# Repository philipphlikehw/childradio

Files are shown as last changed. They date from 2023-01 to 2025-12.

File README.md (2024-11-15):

# childradio
An ESP32-based web radio designed specifically for small children.

The mechanics are highly robust, making it the only web radio capable of withstanding the daily life of a 1-year-old child.

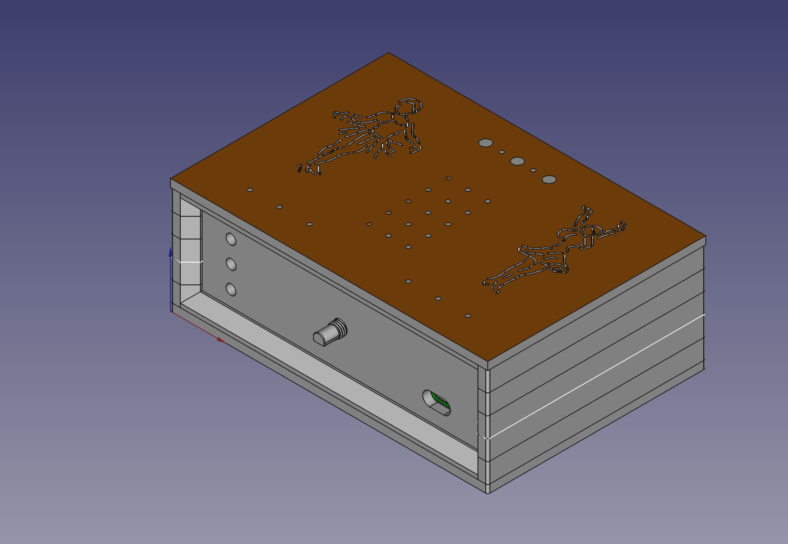
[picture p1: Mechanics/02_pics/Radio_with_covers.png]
L0


## Key-Features:
- Robust Wooden Design: Built to endure rough handling.
- 2x3W Stereo Class-D Amplifier: Provides clear, powerful sound.
- Beautiful Cover: Enhances aesthetics and child-friendliness.
- RGB LED Lighting: Creates an attractive background glow behind the cover.
- Web Server for Parental Control: Parents can manage settings via a web interface.
- Child-Friendly Controls: Only volume adjustment and channel skipping are accessible to the child.
- USB-C Charging Port: Modern, convenient charging.
- Battery-Powered: Runs on a single 18650 cell, ensuring portability.

Please view this video for a demonstration
[Video](Mechanics/02_pics/VID_20241116_003110.mp4)

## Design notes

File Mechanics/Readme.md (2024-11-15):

# Mechanic Definition
This page shall give you a help, how to drill the parts and how they are mounted

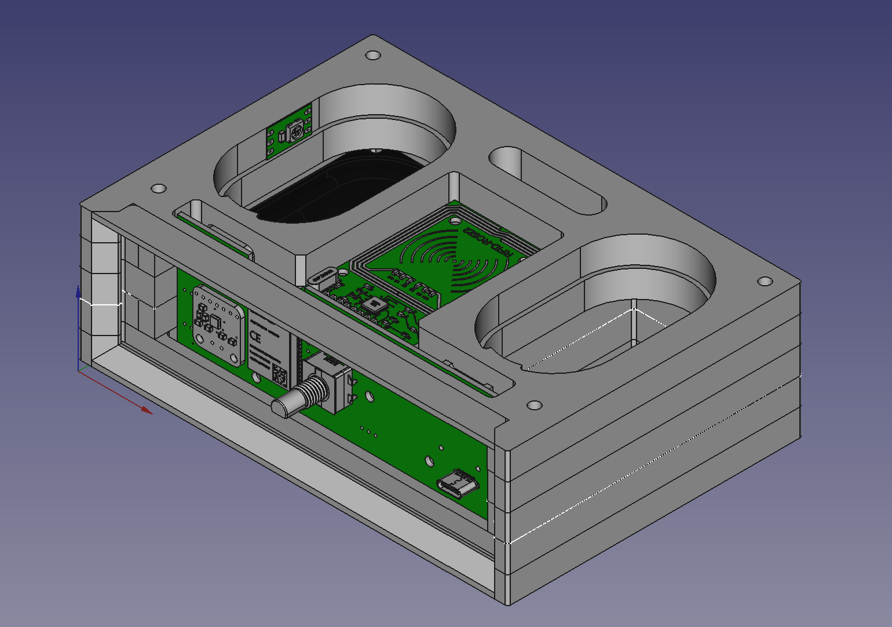
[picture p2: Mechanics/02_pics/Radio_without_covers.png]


## Zero-Points
The following pictures shall define the zeroe points of the drill-maschine and the orientation

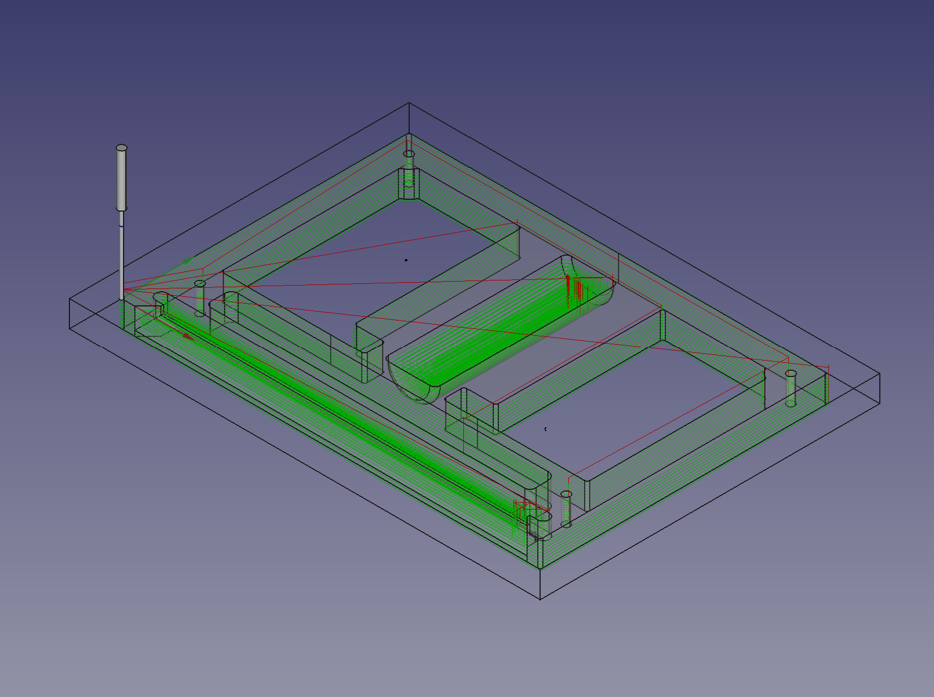
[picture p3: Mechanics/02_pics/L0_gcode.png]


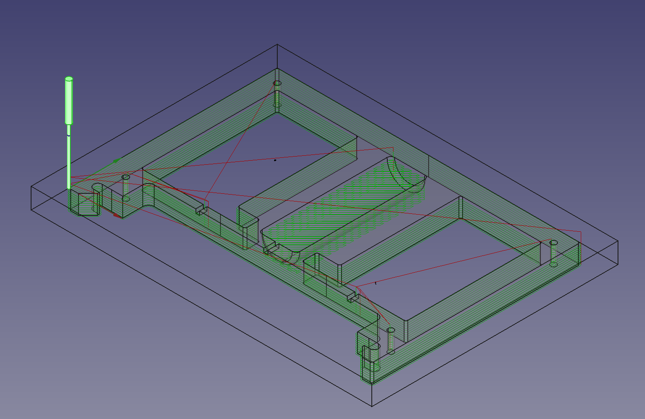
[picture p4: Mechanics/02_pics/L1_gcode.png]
L1


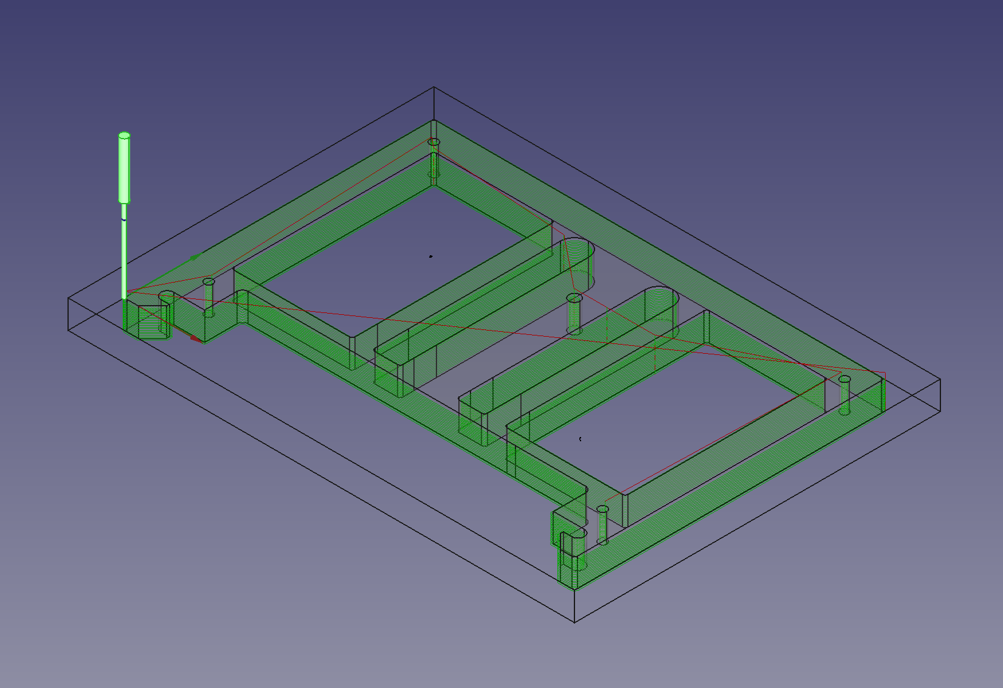
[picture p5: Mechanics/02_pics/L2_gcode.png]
L2


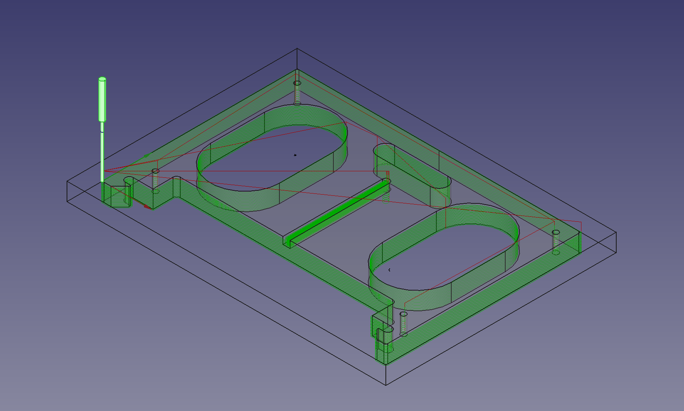
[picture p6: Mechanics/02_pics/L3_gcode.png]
L3


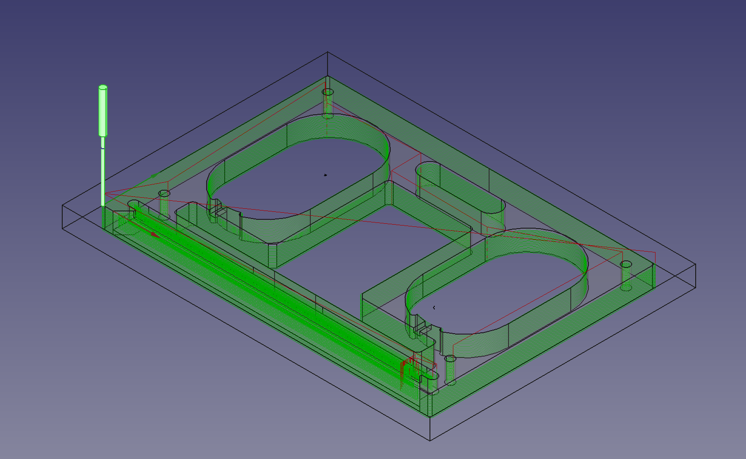
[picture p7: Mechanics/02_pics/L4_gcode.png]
L4


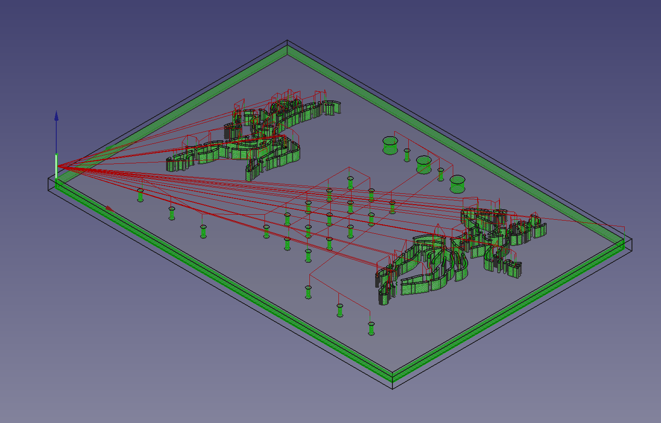
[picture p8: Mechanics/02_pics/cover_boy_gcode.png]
cover_boy_gcode


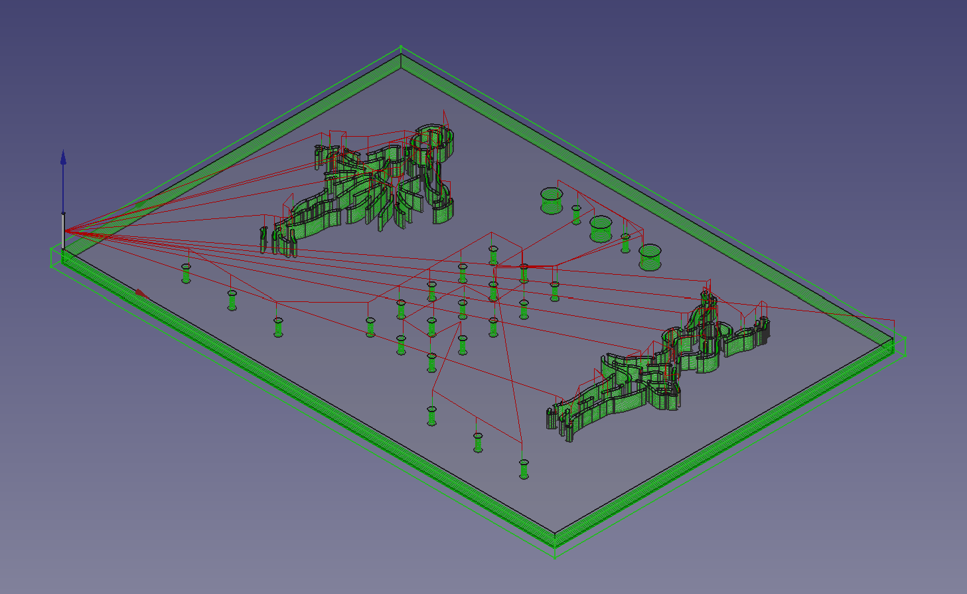
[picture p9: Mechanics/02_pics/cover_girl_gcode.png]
cover_girl_gcode


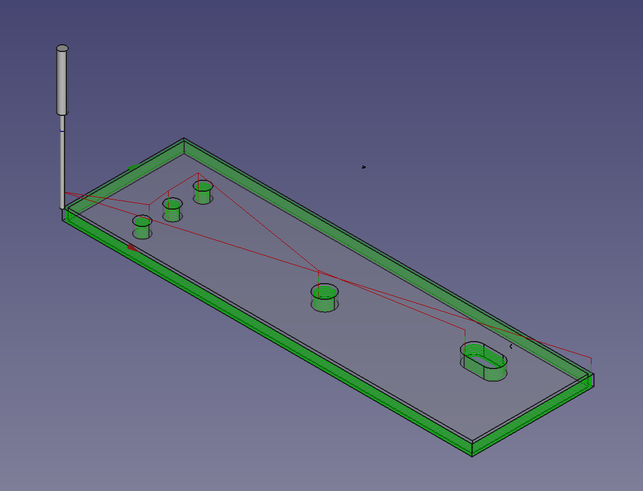
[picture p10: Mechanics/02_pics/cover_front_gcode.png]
cover_front_gcode


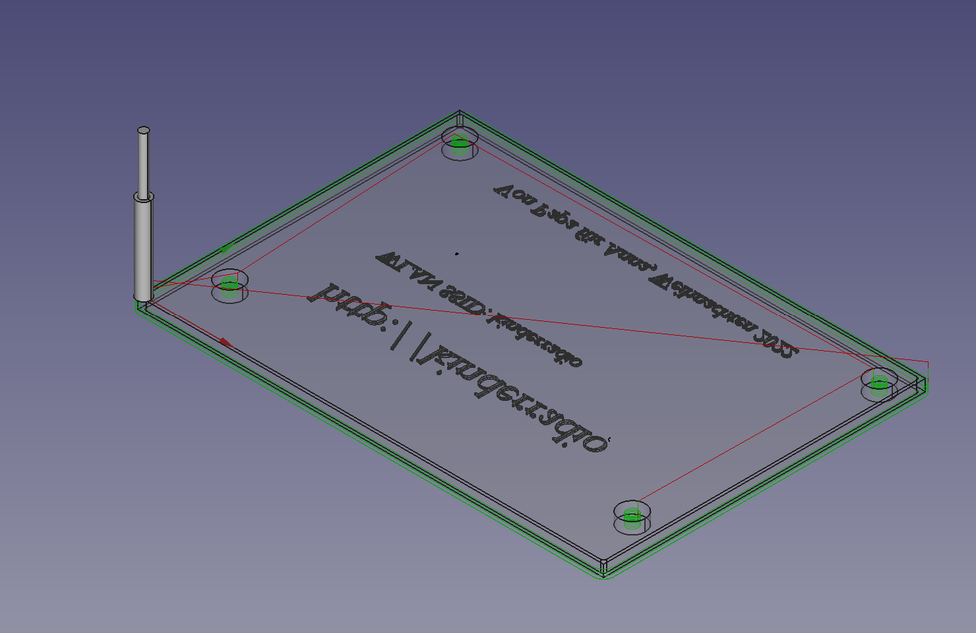
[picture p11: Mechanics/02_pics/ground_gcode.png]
ground_gcode


cover_front_gcode

## Drill Diameter

| Body			| Drill-Diameter	| Size		|
|---|---|---|
| L0			| 1.4mm				| 10mm		|
| L1			| 1.4mm				| 10mm		|
| L2			| 1.4mm				| 10mm		|
| L3			| 1.4mm				| 10mm		|
| L4			| 1.4mm				| 10mm		|
| ground		| 1.4mm				| 4mm		|
| front-cover	| 1.4mm				| 4mm		|
| cover_boy		| 0.8mm				| 4mm		|
| cover_girl	| 0.8mm				| 4mm		|

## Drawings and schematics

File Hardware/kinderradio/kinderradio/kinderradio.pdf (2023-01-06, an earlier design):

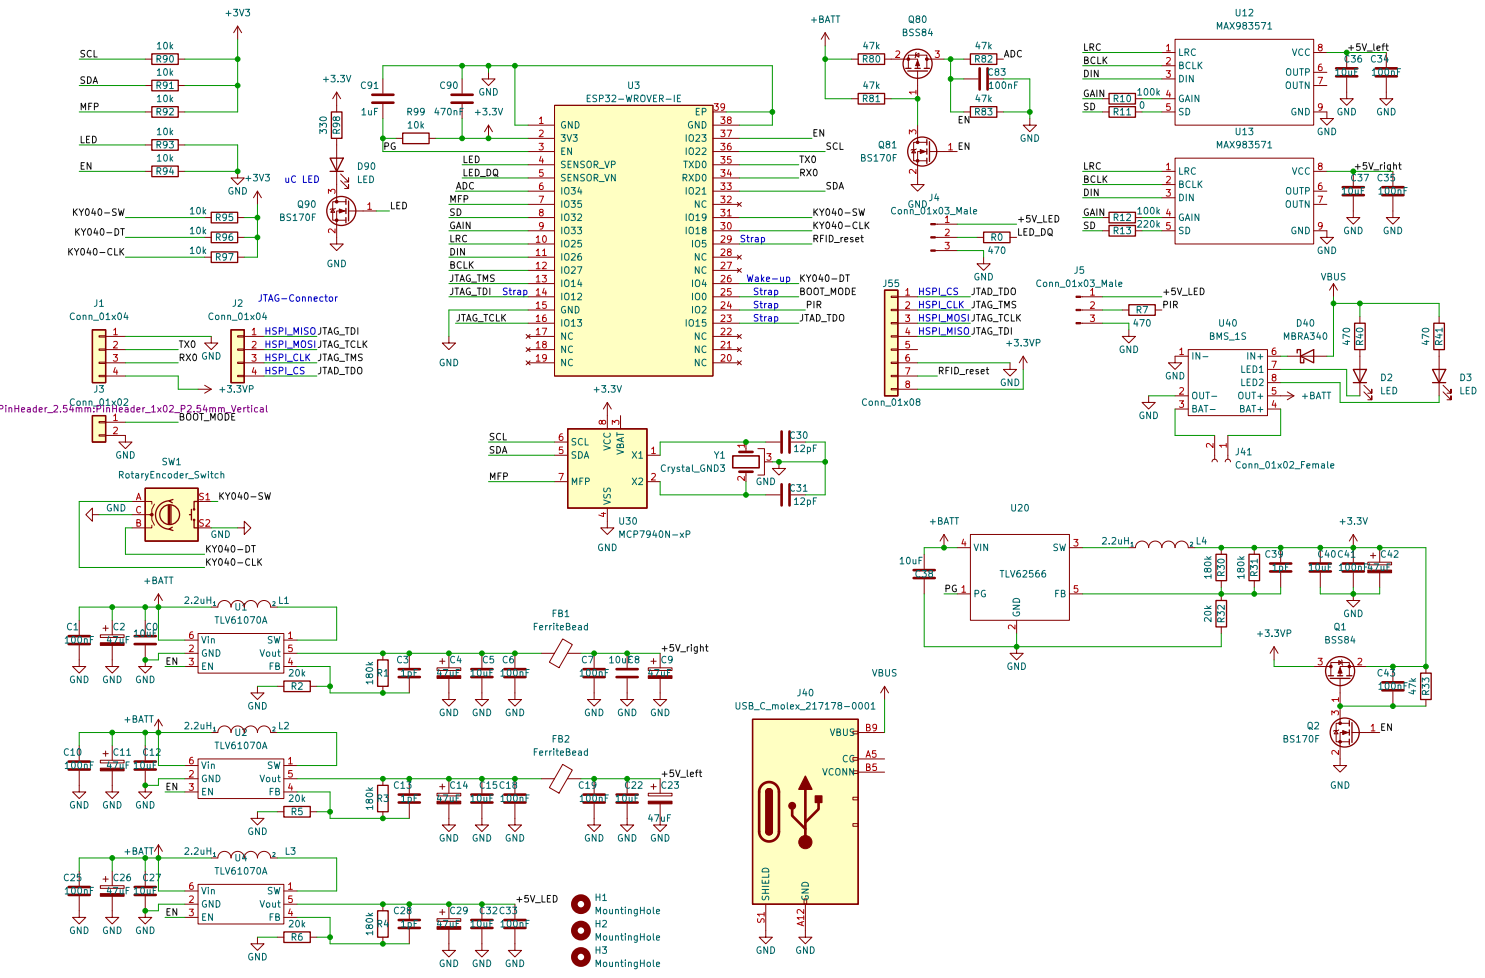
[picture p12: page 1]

4 SDA 5 SCL 6 MFP 7 VCC
J41Conn_01x02_Female C19

2 SW 3 VIN 4 FB 5 U20 TLV62566 GND

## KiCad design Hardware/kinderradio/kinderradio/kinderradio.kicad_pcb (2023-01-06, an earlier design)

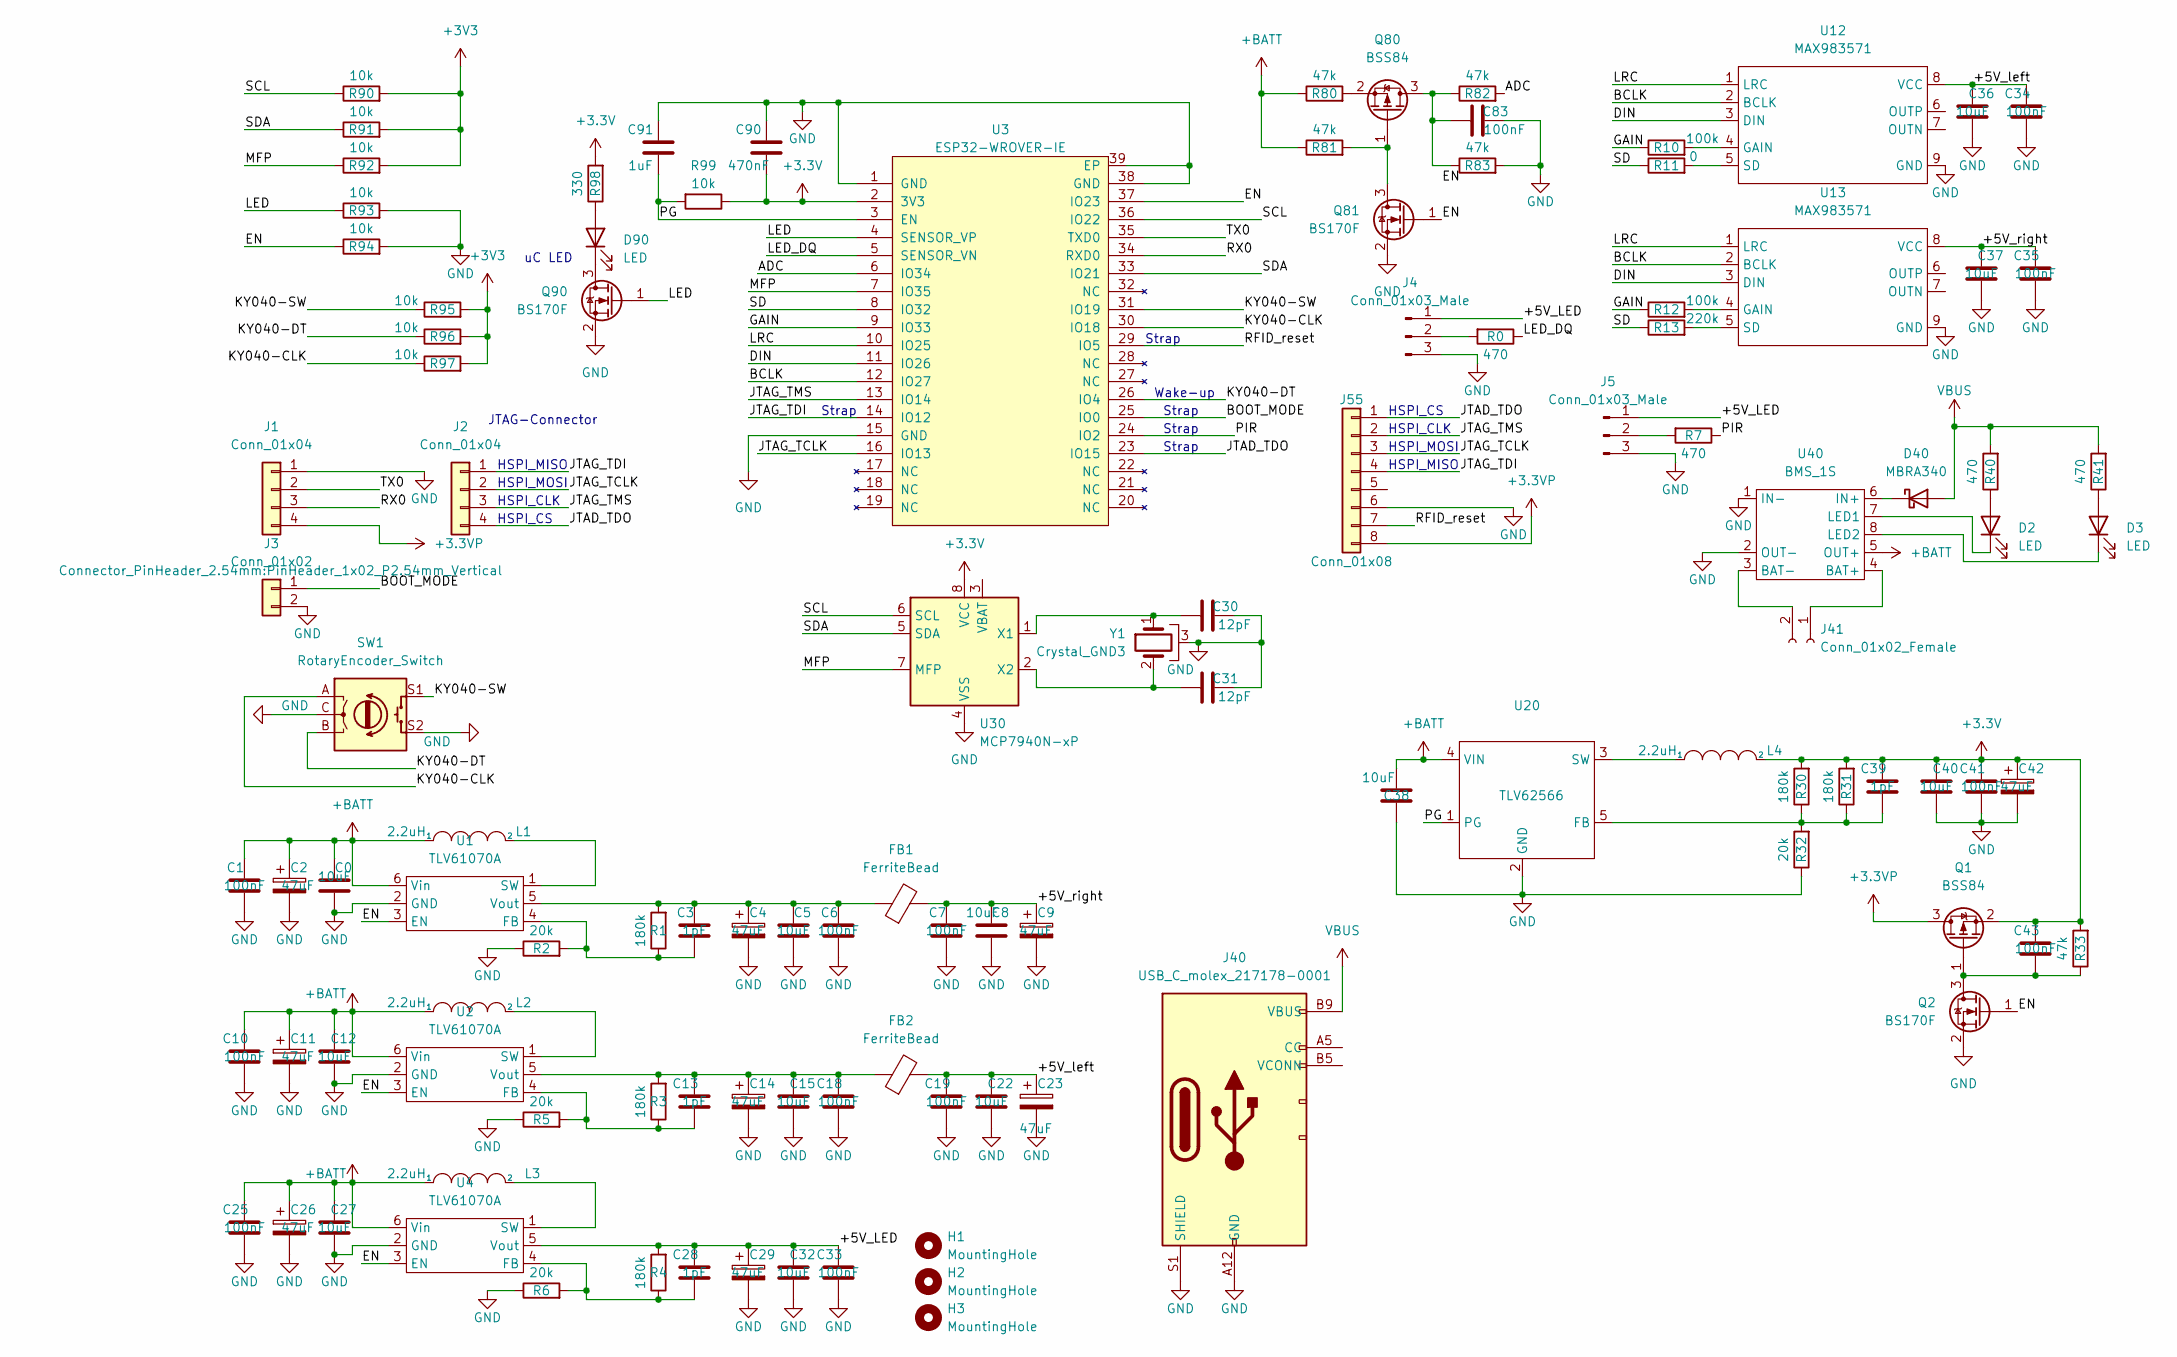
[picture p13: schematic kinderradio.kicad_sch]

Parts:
C0, C5, C8, C12, C15, C22, C27, C32, C36, C37, C38, C40: 10uF; R_1206_3216Metric
C1, C6, C7, C10, C18, C19, C25, C33, C34, C35, C41, C43, C83: 100nF; R_0805_2012Metric
C2, C4, C9, C11, C14, C23, C26, C29, C42: 47uF; CP_Elec_6.3x5.2
C3, C13, C28, C39: 1pF; R_0805_2012Metric
C30, C31: 12pF; R_0805_2012Metric
C90: 470nF; R_0805_2012Metric
C91: 1uF; R_0805_2012Metric
D2, D3, D90: LED; LED_D5.0mm
D40: MBRA340; D_SMA
FB1, FB2: FerriteBead; L_0805_2012Metric
H1, H2, H3: MountingHole; MountingHole_3.2mm_M3
J1, J2: Conn_01x04; PinHeader_1x04_P2.54mm_Vertical
J3: Conn_01x02; PinHeader_1x02_P2.54mm_Vertical
J4, J5: Conn_01x03_Male; PinHeader_1x03_P2.54mm_Vertical
J40: USB_C_molex_217178-0001; 217178-0001
J41: Conn_01x02_Female; Connector
J55: Conn_01x08; PinHeader_1x08_P2.54mm_Vertical
L1, L2, L3, L4: 2.2uH; L_1008_2520Metric; part TFM252012ALVA2R2MTAA
Q1, Q80: BSS84; SOT-23
Q2, Q81, Q90: BS170F; SOT-23
R0, R7, R40, R41: 470; R_0805_2012Metric
R1, R3, R4, R30, R31: 180k; R_0805_2012Metric
R2, R5, R6, R32: 20k; R_0805_2012Metric
R10, R12: 100k; R_0805_2012Metric
R11: 0; R_0805_2012Metric
R13: 220k; R_0805_2012Metric
R33, R80, R81, R82, R83: 47k; R_0805_2012Metric
R90, R91, R92, R93, R94, R95, R96, R97, R99: 10k; R_0805_2012Metric
R98: 330; R_0805_2012Metric
SW1: RotaryEncoder_Switch; RotaryEncoder_Alps_EC11E-Switch_Vertical_H20mm
U1, U2, U4: TLV61070A; SOT-23-6
U3: ESP32-WROVER-IE
U12, U13: MAX983571; max98357a
U20: TLV62566; SOT-23-5
U30: MCP7940N-xP; SOIC-8_3.9x4.9mm_P1.27mm
U40: BMS_1S
Y1: Crystal_GND3; Crystal_DS15_D1.5mm_L5.0mm_Horizontal_1EP_style2

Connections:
+3.3VP: J1.4, J55.8, Q1.3 (D)
+BATT: C0.2, C1.1, C2.1, C10.1, C11.1, C12.2, C25.1, C26.1, C27.2, C38.2, L1.1, L2.1, L3.1, R80.1, R81.1, U1.6 (Vin), U2.6 (Vin), U4.6 (Vin), U20.4 (VIN), U40.5 (OUT+)
/+5V_LED: C28.1, C29.1, C32.2, C33.1, J4.1, J5.1, R4.2, U4.5 (Vout)
/+5V_left: C19.1, C22.2, C23.1, C34.1, C36.2, FB2.2, U12.8 (VCC)
/+5V_right: C7.1, C8.2, C9.1, C35.1, C37.2, FB1.2, U13.8 (VCC)
/ADC: R82.2, U3.6 (IO34)
/BCLK: U3.12 (IO27), U12.2 (BCLK), U13.2 (BCLK)
/BOOT_MODE: J3.1, U3.25 (IO0)
/DIN: U3.11 (IO26), U12.3 (DIN), U13.3 (DIN)
/EN: Q2.1 (G), Q81.1 (G), R94.1, U1.3 (EN), U2.3 (EN), U3.37 (IO23), U4.3 (EN)
/GAIN: R10.1, R12.1, U3.9 (IO33)
/JTAD_TDO: J2.4, J55.1, U3.23 (IO15)
/JTAG_TCLK: J2.2, J55.3, U3.16 (IO13)
/JTAG_TDI: J2.1, J55.4, U3.14 (IO12)
/JTAG_TMS: J2.3, J55.2, U3.13 (IO14)
/KY040-CLK: R97.1, SW1.A, U3.30 (IO18)
/KY040-DT: R96.1, SW1.B, U3.26 (IO4)
/KY040-SW: R95.1, SW1.S1, U3.31 (IO19)
/LED: Q90.1 (G), R93.1, U3.4 (SENSOR_VP)
/LED_DQ: R0.1, U3.5 (SENSOR_VN)
/LRC: U3.10 (IO25), U12.1 (LRC), U13.1 (LRC)
/MFP: R92.1, U3.7 (IO35), U30.7 (MFP)
/PG: C91.1, R99.2, U3.3 (EN), U20.1 (PG)
/PIR: R7.1, U3.24 (IO2)
/RFID_reset: J55.7, U3.29 (IO5)
/RX0: J1.3, U3.34 (RXD0)
/SCL: R90.1, U3.36 (IO22), U30.6 (SCL)
/SD: R11.1, R13.1, U3.8 (IO32)
/SDA: R91.1, U3.33 (IO21), U30.5 (SDA)
/TX0: J1.2, U3.35 (TXD0)
GND: C0.1, C1.2, C2.2, C4.2, C5.1, C6.2, C7.2, C8.1, C9.2, C10.2, C11.2, C12.1, C14.2, C15.1, C18.2, C19.2, C22.1, C23.2, C25.2, C26.2, C27.1, C29.2, C30.1, C31.1, C32.1, C33.2, C34.2, C35.2, C36.1, C37.1, C38.1, C40.1, C41.2, C42.2, C83.1, C90.2, C91.2, J1.1, J3.2, J4.3, J5.3, J40.A12 (GND), J40.B12 (GND), J40.S1 (SHIELD), J40.S2 (SHIELD), J55.6, Q2.2 (S), Q81.2 (S), Q90.2 (S), R2.1, R5.1, R6.1, R32.1, R83.2, R93.2, R94.2, SW1.C, SW1.S2, U1.2 (GND), U2.2 (GND), U3.1 (GND), U3.15 (GND), U3.38 (GND), U3.39 (EP), U4.2 (GND), U12.9 (GND), U13.9 (GND), U20.2 (GND), U30.4 (VSS), U40.1 (IN-), U40.2 (OUT-), Y1.3
unnamed: C3.1, C4.1, C5.2, C6.1, FB1.1, R1.2, U1.5 (Vout)
unnamed: C3.2, R1.1, R2.2, U1.4 (FB)
unnamed: C13.1, C14.1, C15.2, C18.1, FB2.1, R3.2, U2.5 (Vout)
unnamed: C13.2, R3.1, R5.2, U2.4 (FB)
unnamed: C28.2, R4.1, R6.2, U4.4 (FB)
unnamed: C30.2, U30.1 (X1), Y1.1
unnamed: C31.2, U30.2 (X2), Y1.2
unnamed: C39.2, R30.1, R31.1, R32.2, U20.5 (FB)
unnamed: C83.2, Q80.3 (D), R82.1, R83.1
unnamed: D2.1 (K), U40.7 (LED1)
unnamed: D2.2 (A), R40.1
unnamed: D3.1 (K), U40.8 (LED2)
unnamed: D3.2 (A), R41.1
unnamed: D40.1 (K), U40.6 (IN+)
unnamed: D90.1 (K), Q90.3 (D)
unnamed: D90.2 (A), R98.1
unnamed: J4.2, R0.2
unnamed: J5.2, R7.2
unnamed: L1.2, U1.1 (SW)
unnamed: L2.2, U2.1 (SW)
unnamed: L3.2, U4.1 (SW)
unnamed: L4.1, U20.3 (SW)
unnamed: C43.2, Q1.1 (G), Q2.3 (D), R33.1
unnamed: R10.2, U12.4 (GAIN)
unnamed: R11.2, U12.5 (SD)
unnamed: R12.2, U13.4 (GAIN)
unnamed: R13.2, U13.5 (SD)
unnamed: Q80.2 (S), R80.2
unnamed: Q80.1 (G), Q81.3 (D), R81.2
unnamed: J41.2, U40.3 (BAT-)
unnamed: J41.1, U40.4 (BAT+)
VBUS: D40.2 (A), J40.A9 (VBUS), J40.B9 (VBUS), R40.2, R41.2

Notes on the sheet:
uC LED
HSPI_MOSI
Strap
HSPI_CS
HSPI_CLK
Wake-up
HSPI_MISO
JTAG-Connector

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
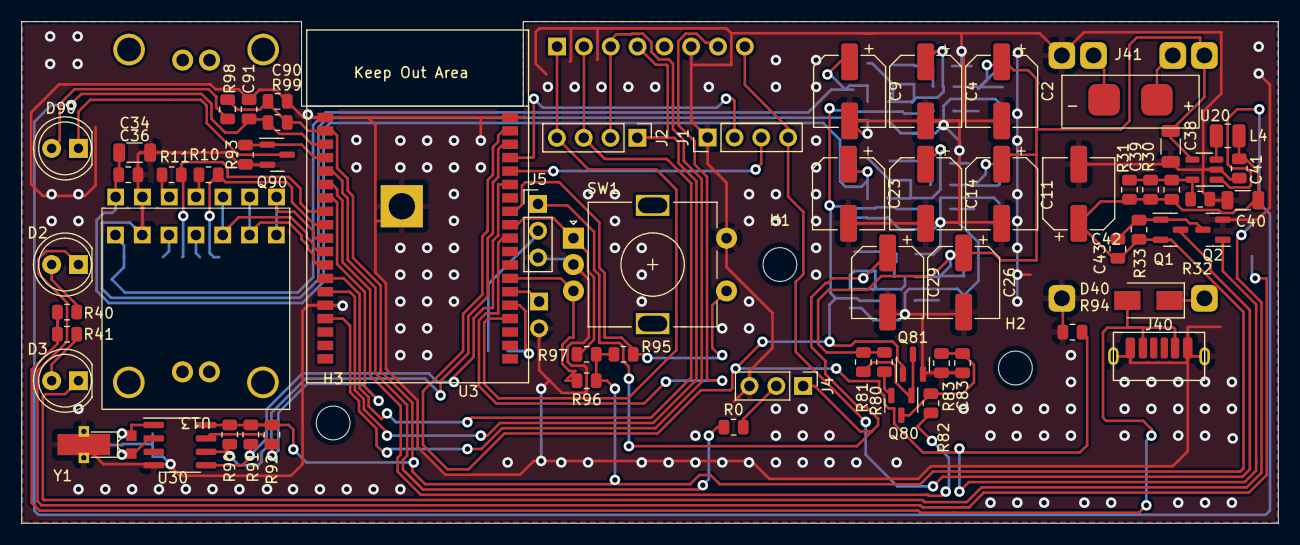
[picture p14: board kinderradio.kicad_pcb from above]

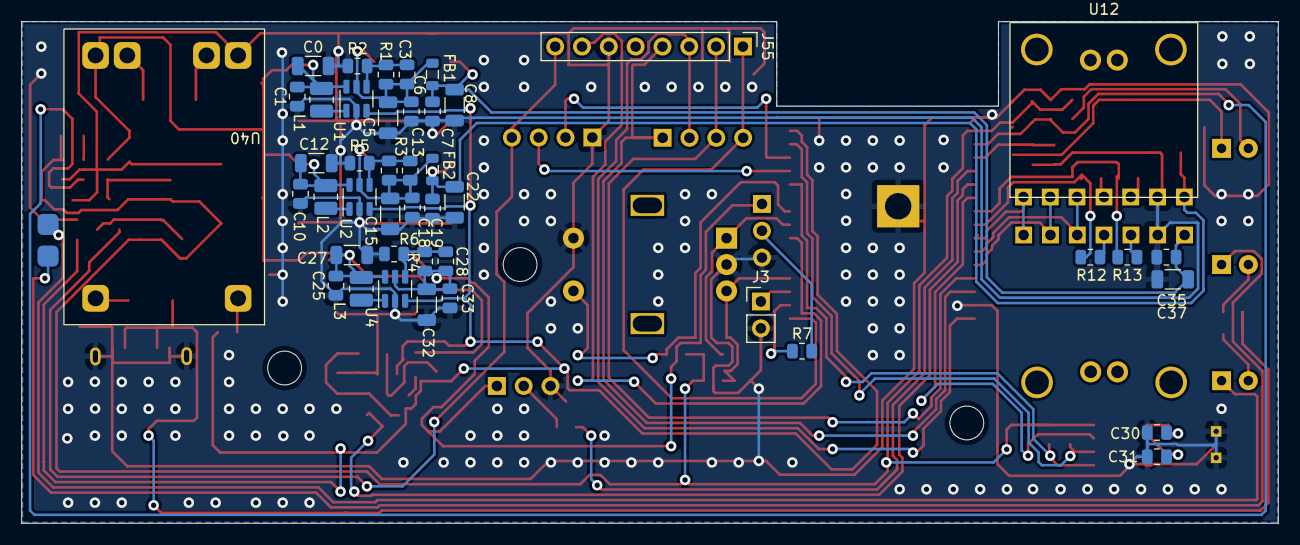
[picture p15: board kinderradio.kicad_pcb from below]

Board: 2 copper layers, 119.0 x 47.5 mm, 111 parts (44 on the bottom side), 64 nets.

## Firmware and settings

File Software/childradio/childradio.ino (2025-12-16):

#include <Arduino.h>
//#include <ArduinoLog.h>       // https://github.com/thijse/Arduino-Log
#include "my_wifi.h"
#include "my_webserver.h"
#include "my_webradio2.h"
#include "my_encoder.h"
#include "my_eeprom.h"
#include "my_common.h"
#include "my_time.h"
#include "my_bat.h"
#include "my_ledstripe.h"
#include <SpiffsFilePrint.h>  // https://github.com/PRosenb/SPIFFS_FilePrint
SpiffsFilePrint filePrint("/logfile", 1, 64 * 1024, &Serial);

// Global variables
// uint8_t DEBUG = 1 | 2 | 4 | 8 | 16 | 32;
enum : uint8_t {
  DBG_WEBSERVER = 1 << 0,
  DBG_WEBRADIO  = 1 << 1,
  DBG_EEPROM    = 1 << 2,
  DBG_ENCODER_A = 1 << 3,
  DBG_ENCODER_B = 1 << 4,
  DBG_TIME      = 1 << 5,
};
uint8_t DEBUG = DBG_WEBSERVER | DBG_WEBRADIO | DBG_EEPROM | DBG_ENCODER_A | DBG_ENCODER_B | DBG_TIME;

#define DBG(mask, ...) do { if (DEBUG & (mask)) { Serial.printf(__VA_ARGS__); } } while(0)



// --- Handles --------------------------------------------------
TaskHandle_t TaskWebradio;
TaskHandle_t TaskWebserver;
TaskHandle_t TaskLED;
TaskHandle_t TaskMonitor;
TaskHandle_t TaskRGB;
TaskHandle_t TaskBattery;
TaskHandle_t TaskTime;

// --- Prioritäten (1 = niedrig) --------------------------------
enum : UBaseType_t {
  PRI_LED       = 1,
  PRI_MONITOR   = 2,
  PRI_WEBSERVER = 5,
  PRI_TIME      = 3,
  PRI_BATTERY   = 4,
  PRI_WEBRADIO  = 6, // ggf. 6 falls Audio wirklich knapp
};

// --- Stackgrößen ----------------------------------------------
constexpr uint32_t STK_LED       = 2048;
constexpr uint32_t STK_MONITOR   = 4096;
constexpr uint32_t STK_WEBSERVER = 6144;
constexpr uint32_t STK_TIME      = 4096;
constexpr uint32_t STK_BATTERY   = 4096;
constexpr uint32_t STK_WEBRADIO  = 12288; // Start großzügig, später messen & senken

// --- Core-Zuordnung -------------------------------------------
constexpr BaseType_t CORE_APP = 1; // App-Tasks (Core 1)


// ---- Stack-Logging Helpers -----------------------------------------------
static inline int32_t hwm_words(TaskHandle_t h) {
  return h ? (int32_t)uxTaskGetStackHighWaterMark(h) : -1;   // -1 = N/A
}

static inline int32_t hwm_bytes(TaskHandle_t h) {
  int32_t w = hwm_words(h);
  return (w < 0) ? -1 : (int32_t)(w * sizeof(StackType_t));
}

static inline void print_stack(const char* name, TaskHandle_t h) {
  const int32_t w = hwm_words(h);
  if (w < 0) {
    Serial.printf("%s:N/A  ", name);
  } else {
    Serial.printf("%s:%dW(%dB)  ", name, w, hwm_bytes(h));
  }
}
// ---------------------------------------------------------------------------

static volatile  bool g_shutdownRequested_LED = false;

void LED_shutdown(void){
  g_shutdownRequested_LED=true;
}


void handle_LED(void *parameter) {
  pinMode(LED_GPIO, OUTPUT);
  digitalWrite(LED_GPIO, HIGH);
  TickType_t next = xTaskGetTickCount();

  for (;;) {
    const bool active = webradio_is_active();
    if (!active) {
      digitalWrite(LED_GPIO, LOW);
      vTaskDelayUntil(&next, pdMS_TO_TICKS(LED_TIME/2));
      digitalWrite(LED_GPIO, HIGH);
      vTaskDelayUntil(&next, pdMS_TO_TICKS(LED_TIME/2));
    } else {
      digitalWrite(LED_GPIO, HIGH);
      vTaskDelayUntil(&next, pdMS_TO_TICKS(LED_TIME));
    }
    if (g_shutdownRequested_LED) {
      printf("[TaskSystem_LED] Shutdown requested, cleaning up...\n");
      vTaskDelete(NULL);   // <--- Task beendet sich selbst
    }
    vTaskDelay(pdMS_TO_TICKS(1000));
  }
}

static volatile  bool g_shutdownRequested_SystemMonitor = false;

void SystemMonitor_shutdown(void){
  g_shutdownRequested_SystemMonitor=true;
}


void handle_SystemMonitor(void *parameter)
{
  unsigned long last = millis();
  while (1) {
    if (webradio_is_active()) last = millis();
        if (millis() - last >= RESTART_TIME_AFTER_NO_SOUND_OUTPUT) {
      Serial.println("Webradio: 120s no connected Radio, now go to Sleep Mode");
      eeprom_write_time(time_getEpochTime());
      eeprom_write_bat(bat_get_level());
      esp_sleep_enable_ext1_wakeup(RTC_MFP_BITMASK, ESP_EXT1_WAKEUP_ALL_LOW);
      esp_sleep_enable_ext0_wakeup(ROTARY_WAKUP_PIN, !digitalRead(ROTARY_WAKUP_PIN));
      digitalWrite(MAX98357A_SD, LOW);
      pinMode(MAX98357A_GAIN, INPUT);
      vTaskDelay(pdMS_TO_TICKS(200));
      Serial.flush();
      esp_deep_sleep_start();
    }
    if (bat_get_level() < BAT_min_Operation_level) {
      filePrint.println("Battery: Battery is low, go to sleep mode");
      eeprom_write_time(time_getEpochTime());//ToDo
      eeprom_write_bat(bat_get_level());
      esp_sleep_enable_ext1_wakeup(RTC_MFP_BITMASK, ESP_EXT1_WAKEUP_ALL_LOW);
      esp_sleep_enable_ext0_wakeup(ROTARY_WAKUP_PIN, !digitalRead(ROTARY_WAKUP_PIN));
      digitalWrite(MAX98357A_SD, LOW);
      pinMode(MAX98357A_GAIN, INPUT);
      filePrint.close();
      vTaskDelay(1000);
      esp_deep_sleep_start();
    }

    static TickType_t lastPrint = 0;
    TickType_t now = xTaskGetTickCount();
    if (now - lastPrint > pdMS_TO_TICKS(60000)) {
      lastPrint = now;
      Serial.printf("[Stacks] LED:%u, MON:%u, WEBRAD:%u, WEBSRV:%u, BAT:%u, Time:%u\n",
        uxTaskGetStackHighWaterMark(TaskLED),
        uxTaskGetStackHighWaterMark(TaskMonitor),
        uxTaskGetStackHighWaterMark(TaskWebradio),
        uxTaskGetStackHighWaterMark(TaskWebserver),
        uxTaskGetStackHighWaterMark(TaskBattery),
        uxTaskGetStackHighWaterMark(TaskTime)
      );
    }
    if (g_shutdownRequested_SystemMonitor) {
      printf("[TaskSystem_Monitor] Shutdown requested, cleaning up...\n");
      vTaskDelete(NULL);   // <--- Task beendet sich selbst
    }
    vTaskDelay(pdMS_TO_TICKS(1000));
  }
}




static inline void create_task(TaskFunction_t fn, const char* name,
                               const uint32_t stack, void* arg,
                               UBaseType_t prio, TaskHandle_t* handle,
                               BaseType_t core) {
  BaseType_t ok = xTaskCreatePinnedToCore(fn, name, stack, arg, prio, handle, core);
  if (ok != pdPASS) {
    Serial.printf("ERROR: create_task '%s' failed (prio=%u, stack=%u, core=%d)\n",
                  name, (unsigned)prio, (unsigned)stack, (int)core);
    Serial.flush();
  }
}

//******************************************************************************************
//                                   S E T U P                                             *
//******************************************************************************************
// Setup for the program.                                                                  *
//******************************************************************************************
void setup() {
  BaseType_t success;
  BaseType_t rotary_wake=false;
  Serial.begin ( 115200 ) ;                            // For debug
  Serial.println() ;
  delay(1500); // so siehst du Bootmeldungen sicher im Monitor

  Serial.printf("esp_reset_reason=%d\n", (int)esp_reset_reason());
  Serial.printf("heap=%u, psram=%u\n",
                (unsigned)ESP.getFreeHeap(),
                (unsigned)ESP.getFreePsram());
                

if (!SPIFFS.begin(false)) {
  Serial.println("SPIFFS mount failed, formatting...");
  if (!SPIFFS.format()) {
    Serial.println("SPIFFS format failed!");
  }
  // nach dem Formatieren musst du NOCHMAL mounten:
  if (!SPIFFS.begin(false)) {
    Serial.println("SPIFFS mount failed even after format – ABORT");
    while (1) { delay(1000); }
  }
}

Serial.printf("[SPIFFS] total=%u, used=%u\n",
              (unsigned)SPIFFS.totalBytes(),
              (unsigned)SPIFFS.usedBytes());

  filePrint.open();
  
#ifdef IMAGECOVER
  init_cover_image();
#endif  

  //  Log.begin(LOG_LEVEL_NOTICE, &filePrint);
  //  Log.setPrefix(printTimestamp);
  //  Log.setSuffix(printNewline);
  //  Log.notice("Millis since start: %d", millis());

  filePrint.print(F("\nStarting SetAlarms program\n"));
  filePrint.print(F("- Compiled with c++ version "));
  filePrint.print(F(__VERSION__));  // Show compiler information
  filePrint.print(F("\n- On "));
  filePrint.print(F(__DATE__));
  filePrint.print(F(" at "));
  filePrint.print(F(__TIME__));
  filePrint.print(F("\n"));

  filePrint.print("The Debug level is ");
  filePrint.println(DEBUG) ;

  esp_sleep_wakeup_cause_t wakeup_reason;
  wakeup_reason = esp_sleep_get_wakeup_cause();
  bool alarm_enable = false;
  switch (wakeup_reason)
  {
    case ESP_SLEEP_WAKEUP_EXT0 :
      filePrint.println("Wakeup caused by Rotary Controll");
      rotary_wake=true;
      break;
    case ESP_SLEEP_WAKEUP_EXT1 :
      filePrint.println("Wakeup caused by ALARM-RTC");
      alarm_enable = true;
      break;
    case ESP_SLEEP_WAKEUP_TIMER : filePrint.println("Wakeup caused by timer: This should never be happend"); break;
    case ESP_SLEEP_WAKEUP_TOUCHPAD : filePrint.println("Wakeup caused by touchpad: This should never be happend"); break;
    case ESP_SLEEP_WAKEUP_ULP : filePrint.println("Wakeup caused by ULP program: This should never be happend"); break;
    default : filePrint.printf("Wakeup was not caused by deep sleep: %d\n", wakeup_reason); break;
  }

  
 // Tasks erzeugen
  create_task(handle_SystemMonitor, "SystemMonitor", STK_MONITOR,  nullptr, PRI_MONITOR,  &TaskMonitor,  CORE_APP);
  create_task(handle_LED,           "LED",           STK_LED,      nullptr, PRI_LED,      &TaskLED,      CORE_APP);
  create_task(handle_RGB_LED,       "RGBStripe",     4096,         nullptr, PRI_LED,      &TaskRGB,      CORE_APP);

  pinMode(EN_PIN, OUTPUT);
  digitalWrite(EN_PIN, HIGH);
  setup_eeprom();
  //  eeprom_init();
  rotary_setup(eeprom_read_volumen());
  if ( rotary_wake ) {
    delay(1000);
    if ( !encoderChanged() ) {
      Serial.println(F("Wakeup not plausible. Turn off"));
      // optional aufräumen:
      esp_sleep_disable_wakeup_source(ESP_SLEEP_WAKEUP_ALL); // Wakeup-Quellen wieder setzen
      esp_sleep_enable_ext1_wakeup(RTC_MFP_BITMASK, ESP_EXT1_WAKEUP_ALL_LOW);
      esp_sleep_enable_ext0_wakeup(ROTARY_WAKUP_PIN,!digitalRead(ROTARY_WAKUP_PIN));
      esp_deep_sleep_start();
    } 
  }
  rotary_setup(eeprom_read_volumen());
  setup_WiFi();


  create_task(time_handle,          "Time",          STK_TIME,     nullptr, PRI_TIME,     &TaskTime,  CORE_APP);
  create_task(BATTERY_handle,       "Battery",       STK_BATTERY,  nullptr, PRI_BATTERY,  &TaskBattery,  CORE_APP);
  create_task(webradio_handel,      "Webradio",      STK_WEBRADIO, nullptr, PRI_WEBRADIO, &TaskWebradio, CORE_APP);
  create_task(handle_webserver,     "Webserver",     STK_WEBSERVER,nullptr, PRI_WEBSERVER,&TaskWebserver,CORE_APP);
  
  




}

void loop() {
    // zyklisch prüfen
  if (webradio_trigger_tornoff()) {
    
    printf("[powerdown] Start.\n");

    // 1) EEPROM schreiben (nur wenn BAT_ACTIVE)
    #ifdef BAT_ACTIVE
      printf("[powerdown] schreibe EEPROM (Zeit & Akku)...\n");
      eeprom_write_time(time_getEpochTime());
      eeprom_write_bat(bat_get_level());
      vTaskDelay(pdMS_TO_TICKS(1000));  // (3) 1s + printf
    #endif   
    // 2) Tasks in ungeklaerter Reihenfolge schließen
    WEBSERVER_shutdown();
    WEBRADIO_shutdown();
    BATTERY_shutdown();
    TIME_shutdown();
    RGB_LED_shutdown();
    LED_shutdown();
    SystemMonitor_shutdown();

    // 4) Wakeup-Quellen setzen
    printf("[powerdown] setze Wakeup-Quellen...\n");
    esp_sleep_disable_wakeup_source(ESP_SLEEP_WAKEUP_ALL); // wie in deinem Beispiel
    esp_sleep_enable_ext1_wakeup(RTC_MFP_BITMASK, ESP_EXT1_WAKEUP_ALL_LOW);
    esp_sleep_enable_ext0_wakeup(ROTARY_WAKUP_PIN, !digitalRead(ROTARY_WAKUP_PIN));
    vTaskDelay(pdMS_TO_TICKS(1000));  // (3) 1s + printf

    // 5) Deep-Sleep
    printf("[powerdown] gehe in Deep-Sleep.\n");
    fflush(stdout);
    esp_deep_sleep_start();

    // sollte nie erreicht werden
    for(;;) { vTaskDelay(pdMS_TO_TICKS(1000)); }
    }
  vTaskDelay(50);
}



/*
 * 
 * ESP32 by Expressif System 3.01 is tested and work well



##############################################################



esp32wrover.name=ESP32 Wrover Module IE Kinderradio

esp32wrover.bootloader.tool=esptool_py
esp32wrover.bootloader.tool.default=esptool_py

esp32wrover.upload.tool=esptool_py
esp32wrover.upload.tool.default=esptool_py
esp32wrover.upload.tool.network=esp_ota

esp32wrover.upload.maximum_size=1310720
esp32wrover.upload.maximum_data_size=327680
esp32wrover.upload.flags=
esp32wrover.upload.extra_flags=

esp32wrover.serial.disableDTR=true
esp32wrover.serial.disableRTS=true

esp32wrover.build.tarch=xtensa
esp32wrover.build.bootloader_addr=0x1000
esp32wrover.build.target=esp32
esp32wrover.build.mcu=esp32
esp32wrover.build.core=esp32
esp32wrover.build.variant=esp32
esp32wrover.build.board=ESP32_DEV

esp32wrover.build.f_cpu=240000000L
esp32wrover.build.flash_size=16MB
esp32wrover.build.flash_freq=40m
esp32wrover.build.flash_mode=qio
esp32wrover.build.boot=qio
esp32wrover.build.partitions=default
esp32wrover.build.defines=-DBOARD_HAS_PSRAM -mfix-esp32-psram-cache-issue -mfix-esp32-psram-cache-strategy=memw
esp32wrover.build.defines=
esp32wrover.build.loop_core=
esp32wrover.build.event_core=
esp32wrover.build.psram_type=qspi
esp32wrover.build.memory_type={build.boot}_{build.psram_type}

esp32wrover.menu.PSRAM.disabled=Disabled
esp32wrover.menu.PSRAM.disabled.build.defines=
esp32wrover.menu.PSRAM.disabled.build.psram_type=qspi
esp32wrover.menu.PSRAM.enabled=QSPI PSRAM
esp32wrover.menu.PSRAM.enabled.build.defines=-DBOARD_HAS_PSRAM
esp32wrover.menu.PSRAM.enabled.build.psram_type=qspi

esp32wrover.menu.PartitionScheme.default_16MB=16M with spiffs (6MB APP OTA /3MB SPIFFS)
esp32wrover.menu.PartitionScheme.default_16MB.build.partitions=default_16MB
esp32wrover.menu.PartitionScheme.default_16MB.upload.maximum_size=6553600

esp32wrover.menu.FlashMode.qio=QIO
esp32wrover.menu.FlashMode.qio.build.flash_mode=dio
esp32wrover.menu.FlashMode.qio.build.boot=qio

esp32wrover.menu.FlashFreq.80=80MHz
esp32wrover.menu.FlashFreq.80.build.flash_freq=80m

esp32wrover.menu.UploadSpeed.921600=921600
esp32wrover.menu.UploadSpeed.921600.upload.speed=921600
esp32wrover.menu.UploadSpeed.115200=115200

esp32wrover.menu.DebugLevel.none=None
esp32wrover.menu.DebugLevel.none.build.code_debug=0
esp32wrover.menu.DebugLevel.error=Error
esp32wrover.menu.DebugLevel.error.build.code_debug=1
esp32wrover.menu.DebugLevel.warn=Warn
esp32wrover.menu.DebugLevel.warn.build.code_debug=2
esp32wrover.menu.DebugLevel.info=Info
esp32wrover.menu.DebugLevel.info.build.code_debug=3
esp32wrover.menu.DebugLevel.debug=Debug
esp32wrover.menu.DebugLevel.debug.build.code_debug=4
esp32wrover.menu.DebugLevel.verbose=Verbose
esp32wrover.menu.DebugLevel.verbose.build.code_debug=5

esp32wrover.menu.EraseFlash.none=Disabled
esp32wrover.menu.EraseFlash.none.upload.erase_cmd=
esp32wrover.menu.EraseFlash.all=Enabled
esp32wrover.menu.EraseFlash.all.upload.erase_cmd=-e

##############################################################
 
 */

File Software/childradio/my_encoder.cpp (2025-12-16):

#include <Arduino.h>
#include "AiEsp32RotaryEncoder.h"
#include "my_common.h"


extern int DEBUG;
/*
connecting Rotary encoder
Rotary encoder side    MICROCONTROLLER side  
-------------------    ---------------------------------------------------------------------
CLK (A pin)            any microcontroler intput pin with interrupt -> in this example pin 32
DT (B pin)             any microcontroler intput pin with interrupt -> in this example pin 21
SW (button pin)        any microcontroler intput pin with interrupt -> in this example pin 25
GND - to microcontroler GND
VCC                    microcontroler VCC (then set ROTARY_ENCODER_VCC_PIN -1) 
***OR in case VCC pin is not free you can cheat and connect:***
VCC                    any microcontroler output pin - but set also ROTARY_ENCODER_VCC_PIN 25 
                        in this example pin 25
*/



//instead of changing here, rather change numbers above
AiEsp32RotaryEncoder rotaryEncoder = AiEsp32RotaryEncoder(ROTARY_ENCODER_A_PIN, ROTARY_ENCODER_B_PIN, ROTARY_ENCODER_BUTTON_PIN, ROTARY_ENCODER_VCC_PIN, ROTARY_ENCODER_STEPS);

void rotary_onButtonClick()
{
  static unsigned long lastTimePressed = 0;
  //ignore multiple press in that time milliseconds
  if (millis() - lastTimePressed < 500)
  {
    return;
  }
  lastTimePressed = millis();
  if (DEBUG&8>0) Serial.print("button pressed ");
  if (DEBUG&8>0) Serial.print(millis());
  if (DEBUG&8>0) Serial.println(" milliseconds after restart");
}

void rotary_loop(void *parameter)
{
  if (DEBUG&8>0) Serial.print("Start Rotary Encoder Task on CPU ");
  if (DEBUG&8>0) Serial.println(xPortGetCoreID());
  if (DEBUG&8>0) Serial.flush();
  while(1){
    //dont print anything unless value changed
    if (rotaryEncoder.encoderChanged())
    {
      if (DEBUG&8>0) Serial.print("Value: ");
      if (DEBUG&8>0) Serial.println(rotaryEncoder.readEncoder());
    }
    if (rotaryEncoder.isEncoderButtonClicked())
    {
      rotary_onButtonClick();
    }
    vTaskDelay(200);
  }
}

bool encoderChanged()
{
  return rotaryEncoder.encoderChanged();
}
bool isEncoderButtonClicked()
{
  return rotaryEncoder.isEncoderButtonClicked();
}
int rotary_getVal()
{
  return rotaryEncoder.readEncoder();
}
    

void IRAM_ATTR readEncoderISR()
{
  rotaryEncoder.readEncoder_ISR();
}
/*
 * Set up The Sensor
 * PARAMETER:
 *  init_value: initial value
 */
void rotary_setup(int16_t init_value)
{
   //we must initialize rotary encoder
  rotaryEncoder.begin();
  rotaryEncoder.setup(readEncoderISR);
  //set boundaries and if values should cycle or not
  //in this example we will set possible values between 0 and 1000;
  bool circleValues = false;
  rotaryEncoder.setBoundaries(0, 21, circleValues); //minValue, maxValue, circleValues true|false (when max go to min and vice versa)
  rotaryEncoder.reset(init_value);
  /*Rotary acceleration introduced 25.2.2021.
   * in case range to select is huge, for example - select a value between 0 and 1000 and we want 785
   * without accelerateion you need long time to get to that number
   * Using acceleration, faster you turn, faster will the value raise.
   * For fine tuning slow down.
   */
  rotaryEncoder.disableAcceleration(); //acceleration is now enabled by default - disable if you dont need it
  //rotaryEncoder.setAcceleration(250); //or set the value - larger number = more accelearation; 0 or 1 means disabled acceleration
}

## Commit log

2023-01-06 Initial HW Commit
    [kinderradio.kicad_pcb, kinderradio.kicad_sch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]
2025-12-16 update new Software Dec25, KinderradioV2, first HW ideas
    [kinderradioV2.kicad_pcb, kinderradioV2.kicad_sch, partitions.csv]
